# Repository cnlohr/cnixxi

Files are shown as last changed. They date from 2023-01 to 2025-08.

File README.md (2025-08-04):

# cnixxi

My experiment with nixie tubes.

It uses a ch32v003 to both control the nixie tube's cathodes, as well as provide the 180V supply for the nixie tube.

Youtube video:

Powering Nixies off USB with a 10¢ Micro (https://www.youtube.com/watch?v=-4d3PgEXhdY)

Schematic:

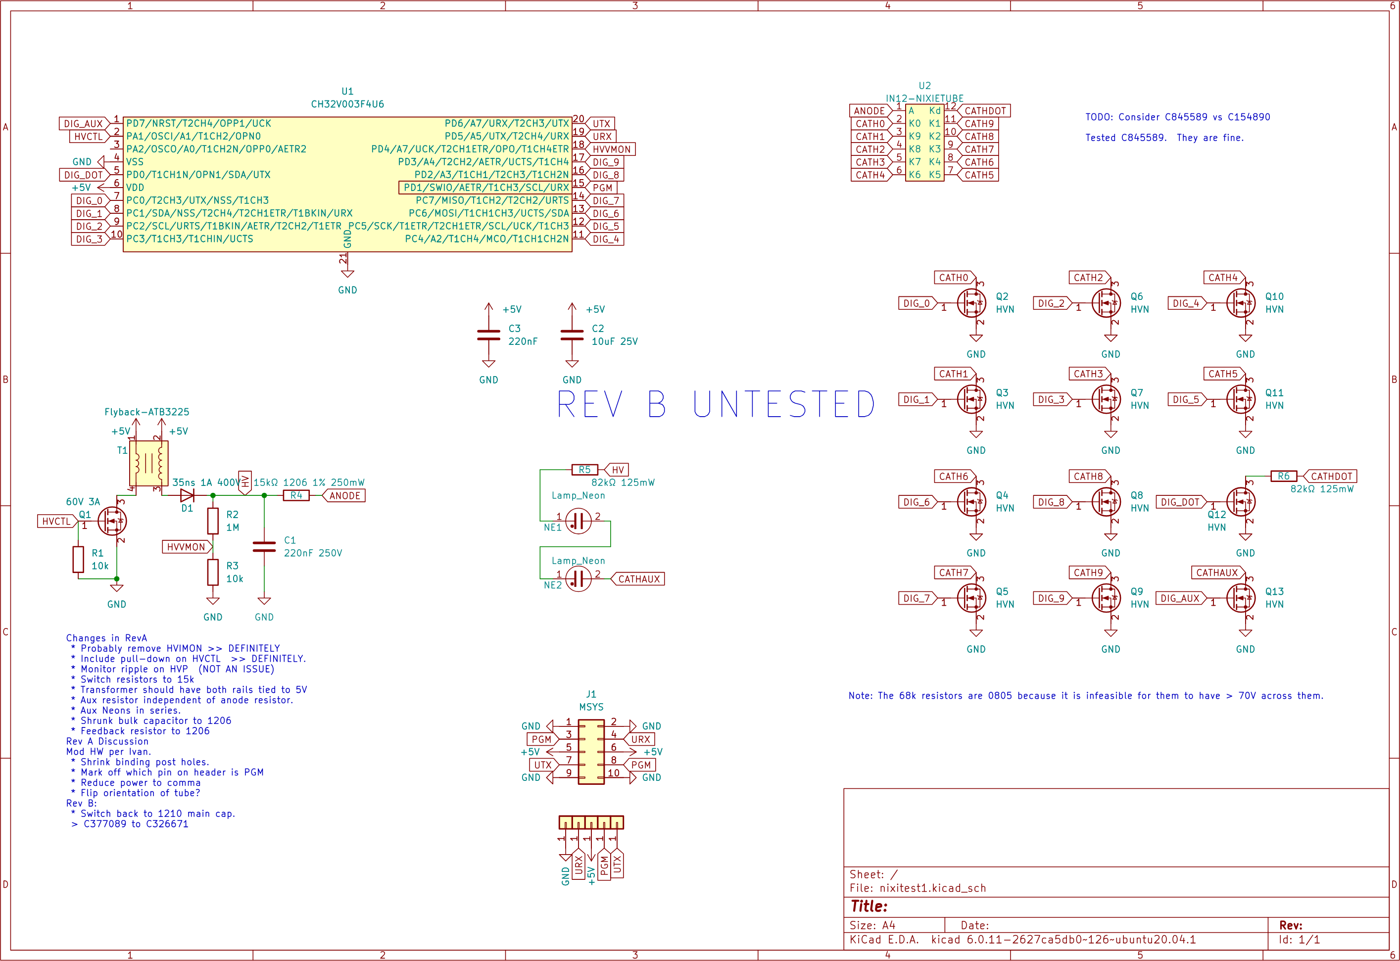
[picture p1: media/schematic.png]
schematic


Board:

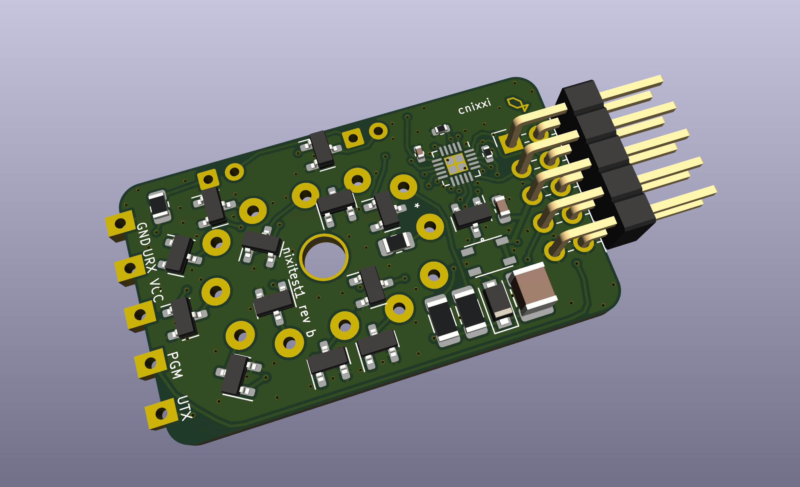
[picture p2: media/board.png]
board


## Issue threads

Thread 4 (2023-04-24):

Add wish list to core nixxi

cnlohr, 2023-04-24:
First: Use an extra IO pin to soldered header.

 * WS2812B Emulation
 * TX/RX Serial Protocol

cnlohr, 2023-04-24:
Use TXCO on main board. C427551 << Probably the winrar.

cnlohr, 2023-04-24:
It looks like C135223 is actually better?

cnlohr, 2023-04-24:
Also check C253754

cnlohr, 2023-04-28:
* Software-wise, try to use expected addition for de-noising the signal.  I.e. if tube is on apply constant offset.

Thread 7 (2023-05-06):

Love the concept - request for variation

LouDou, 2023-05-06:
Hi,

I saw this pop up on my YT feed - very interesting and love the concept of an addressable PWM driver for nixie tubes.

I actually have a small stash (now 14; I had 20 in total, but already built a clock using an off-the-shelf board which requires 6) of IN-17 tubes which are a bit smaller (and IMO way cuter :wink:) than the IN-12 you've used.

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

So, could the design be altered to suit the footprint of the IN-17? And is it electrically compatible?

Regards,
Doug

cnlohr, 2023-05-07:
Oh wow! Yes. It should be pretty portable. http://www.tube-tester.com/sites/nixie/dat_arch/IN-17_02.pdf

I also picked up a bunch of IN-4's.  I might poke around to see if I can figure something neat out.

isparkes, 2023-06-09:
IN-4s have a bad reputation for failing - they are not mercury doped and form whiskers between the digits after a while. IN-1 have the same problem. Not saying don't use them, just be aware that you should provide a way of easily changing the tubes , e.g. by using 1mm machine pins.

A possible optimisation: I have used BSS131 in the past for the cathode drivers - they are a bit cheaper and work just fine. I used them in this proof of concept back in 2018 https://bitbucket.org/isparkes/nixiemodulei2c/ - you'll notice that I used a higher cost controller back then, and managed to squeeze a NeoPixel into the design as well... :D

isparkes, 2023-06-09:
Oh, forgot to say what I actually wanted to say: Love what you've done with that controller! If there's anything I can help out with on with the Nixie specific stuff, feel free to ask. I've had a Nixie obsesession since 2018 or so and know my way around pretty well by now.

ImNoahDev, 2025-05-16:
I see its been a while but did you work this out? I was looking at making a variation for in13 tubes.

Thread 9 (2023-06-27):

Add PDF of schematic to repository?

jcwren, 2023-06-27:
Would you mind adding a PDF file of the schematic to the repo, please?

cnlohr, 2023-06-27:
It's here: https://github.com/cnlohr/cnixxi/blob/master/nixitest1/nixitest1.pdf

Or did I miss something?

jcwren, 2023-06-27:
Partially my bad :)  I was looking in `esp32s2-nixiehost`

cnlohr, 2023-06-28:
Oh, that's pretty separate.

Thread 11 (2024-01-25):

KiCad version

vzreagle, 2024-01-25:
Hi, I'm using KiCad 5.1.5 on Ubuntu 20.04 and can't open the schematics. Which version you are using? Thanks, nice project!

vzreagle, 2024-02-14:
Yes, I can use the PDF and make my own design, because I want to use only your high voltage generator for another function. But I want to know exactly what transistor you used, because I looked for one with similar characteristics (MOSFET N-CHANNEL 200V 1A) on Mouser and Digikey, and they are very expensive and with packages that do not work for me. Did you buy it at LCSC? could you provide the link? Thanks

cnlohr, 2024-02-15:
You can look into the production files here https://github.com/cnlohr/cnixxi/blob/master/nixitest1/nixitest1-revB.zip

The inner CSV has the BOM.

[nixitest1.csv](https://github.com/cnlohr/cnixxi/files/14289801/nixitest1.csv)

I ended up going with a C2938374 for the high-power switch and C845589 for the individual segments.

Closed 2024-02-01.

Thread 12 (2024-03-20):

Buy PCB premade

ImNoahDev, 2024-03-20:
Hi, Is there anywhere I can buy these driver PCBs pre-made. I would love to get some for my projects

jet438, 2025-05-02:
I too would like to know.

cnlohr, 2025-05-05:
You know... I made a couple.  I wonder if I can find them.  I'll leave this unresolved for the time being.  How many boards would you guys want if I did find them?

jet438, 2025-05-09:
Any update if you found the boards or not?

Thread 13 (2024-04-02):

Add USB control support over rv003usb

JustusFluegel, 2024-04-02:
Hi there, just came across your videos on youtube.

Since you released the `rv0003usb` library after this project was "complete" I thought it might make sense to use that here, if possible (note that I have not looked at the code thus far and I am not sure if for example the pid control loop and usb interrupt could interfere with each others timings in some way) and since you mentioned you wish to use this via usb in the video I just thought to at least throw the idea in the room.

Feel free to just ignore/close this if there is no interest in that, just a thing that  came across my mind :) ( and certainly don't feel pressured to make any changes here, if I wish to use this I can work on this myself (and create a pr afterwards if desired), again, this is just an idea that crossed my mind )

cnlohr, 2024-04-03:
To clarify, this project doesn't use usb at all, it uses a programmer to talk over the SWIO interface to alter the control loop, etc.

It would not be feasible to drive the nixi tube and also be a USB slave at the same time, it would cause serious timing issues in the feedback loop for the boost supply.

Sorry if that quashes any dreams.

JustusFluegel, 2024-04-03:
Fair enough, was kinda a long shot anyways (to clarify: I was aware that this doesn't use usb in it's current state, just was interested if it would be theoretically possible to add).

Thanks for taking your time to answer tho!

Closed 2024-04-03.

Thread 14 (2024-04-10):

Reason of using ADC injection channel for Vref

monte-monte, 2024-04-10:
Hi. I'm reading your code, trying to adapt it for my needs. Can you explain why do you read Vref in a separate injection group? What difference does it make compared to measuring both channels in the rule group?
Is it to read Vref on separate timer trigger after HVMON channel is converted?
Also I am reading the reference manual and there is this note:
```
Note: 1. When converting a rule group or injection group in intermittent mode, the conversion sequence does
not automatically start from the beginning when it ends. When all subgroups have been converted, the next
trigger event starts the conversion of the first subgroup.
2. You cannot use auto-injection (JAUTO=1) and intermittent mode at the same time.
```
So does it mean that Vref is being read 2 times in a row?
Also this line:
https://github.com/cnlohr/cnixxi/blob/d3db1aef0dade1c4579eeff3b5d0570b02ada58f/firmware/nixitest1/nixitest1.c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
contradicts the second paragraph of the note above.

Sorry if it's annoying, I am just confused "a little" :)

monte-monte, 2024-04-10:
Ok, so sometimes it's better to think a bit longer before asking questions:)
I guess you just want to have two registers with two voltages updated per every ADC interrupt, that's why injection mode.

But the second question stands: do ``ADC_JDISCEN`` and ``ADC_JEOCIE`` work together? And if they do, does injection group get sampled twice?

monte-monte, 2024-04-10:
So, I have made a simple boost converter, with an inductor instead of flyback transformer to drive 12-15V leds from 5V. I played with tuning values but couldn't get rid of visible brightness fluctuations that are visible when led is running at low power. I concluded, that it was not ripple from PWM but the PID truing to compensate.
First I increased sample time for feedback reading and decreased for VDD. Then I removed ``ADC_JDISCEN`` from ADC setup and now I don't have fluctuations even with simple version of your PID (that has only the proportional part).

monte-monte, 2024-04-11:
I used ADC DMA example from ch32v003fun to adapt this code to use DMA. Now ``SetupADC`` looks like this:
```
        // Configure ADC.
	// PD4 is analog input chl 7
	GPIOD->CFGLR &= ~(0xf<<(4*4));	// CNF = 00: Analog, MODE = 00: Input

	// Reset the ADC to init all regs
	RCC->APB2PRSTR |= RCC_APB2Periph_ADC1;
	RCC->APB2PRSTR &= ~RCC_APB2Periph_ADC1;

	// ADCCLK = 12 MHz => RCC_ADCPRE divide by 4
	RCC->CFGR0 &= ~RCC_ADCPRE;  // Clear out the bis in case they were set
	RCC->CFGR0 |= RCC_ADCPRE_DIV4;	// set it to 010xx for /4.

	// Set up single conversion on chl 7
	ADC1->RSQR1 = (ADC_NUMCHLS-1) << 20;
	ADC1->RSQR2 = 0;
	ADC1->RSQR3 = (7<<(5*0)) | (8<<(5*1));

	// Sampling time for channels. Careful: This has PID tuning implications.
	// Note that with 3 and 3,the full loop (and injection) runs at 138kHz.
	ADC1->SAMPTR2 = (1<<(3*7)) | (1<<(3*8));
		// 0:7 => 3/9/15/30/43/57/73/241 cycles
		// (4 == 43 cycles), (6 = 73 cycles)  Note these are alrady /2, so
		// setting this to 73 cycles actually makes it wait 256 total cycles
		// @ 48MHz.

	// Turn on ADC and set rule group to sw trig
	// 0 = Use TRGO event for Timer 1 to fire ADC rule.
	ADC1->CTLR2 = ADC_ADON | ADC_EXTTRIG | ADC_DMA;

	// Reset calibration
	ADC1->CTLR2 |= ADC_RSTCAL;
	while(ADC1->CTLR2 & ADC_RSTCAL);

	// Calibrate ADC
	ADC1->CTLR2 |= ADC_CAL;
	while(ADC1->CTLR2 & ADC_CAL);

	// Turn on DMA
	RCC->AHBPCENR |= RCC_AHBPeriph_DMA1;

	//DMA1_Channel1 is for ADC
	DMA1_Channel1->PADDR = (uint32_t)&ADC1->RDATAR;
	DMA1_Channel1->MADDR = (uint32_t)adc_buffer;
	DMA1_Channel1->CNTR  = ADC_NUMCHLS;
	DMA1_Channel1->CFGR  =
		DMA_M2M_Disable |
		DMA_Priority_VeryHigh |
		DMA_MemoryDataSize_HalfWord |
		DMA_PeripheralDataSize_HalfWord |
		DMA_MemoryInc_Enable |
		DMA_Mode_Circular |
		DMA_DIR_PeripheralSRC;

	// Turn on DMA channel 1
	DMA1_Channel1->CFGR |= DMA_CFGR1_EN;

	// enable the ADC Conversion Complete IRQ
	NVIC_EnableIRQ( ADC_IRQn );

	// ADC_JEOCIE: Enable the End-of-conversion interrupt.
	// ADC_SCAN: Allow scanning.
	ADC1->CTLR1 = ADC_EOCIE | ADC_SCAN;
```

And in ``ADC1_IRQHandler`` I read values from ``adc_buffer[0]`` and ``adc_buffer[1]`` respectively. Now everything works even with low sampling time, but with my hardware setup I still get better result from using just proportional part of PID. If I try to use full PID I get brightness fluctuations that are not reflected in voltage monitor in ``testnix`` app. I guess I'd need to dive deeper into PID tuning for it to work perfectly for me, but for now I don't see much reason. But I'd like to better understand what causes this difference in behavior.
When using full PID it seems like timing of ADC reads plays a big role, such if I change sampling times I see different behavior, with only proportional I don't see any visible change.
The next step will be to try implement constant current mode with use of another ADC channel and built-in OPAMP.

monte-monte, 2024-04-13:
Continuing tinkering I've soldered 3.3V LDO to supply power from the same source as the boost part of the circuit (before MCU was powered via WCH-link). Now I see a slight brightness ripple at low power. I've concluded that the noisy VDD readings are a culprit here. If I set VDD hardcoded to 3.3V value the brightness ripple is gone.
BUT! The strange part event with live VDD readings the ripple is only present when testnix app is running. If I close the app, even without detaching a probe, the ripple is gone. So does DMDATA0 reads and writes introduce some timing lag, or what? I haven't got an oscilloscope, so I can't accurately test such fast signals.

cnlohr, 2024-04-22:
I am so sorry, I have been so heads down on porting the ch32x035 stuff, I have been neglecting my github...  But to summarize things for anyone else coming along,

1. I measure VCC with the injection, because VCC is the voltage reference for all other measurements, you need to know your VCC if you want to know the voltage of your other measured voltages.
2. I regret that I don't recall the specifics surrounding how the injection stuff works, I barely understood it when I wrote the code to begin with :(
3. Looking at your code, I am still unclear what it's measuring with the rule and what it's measuring with the injection.
4. **ADC TIMING MATTERS MASSIVELY**  You MUST align your ADC sampling with your PWM switch.  For some applications it must be on the "on" and others it must be on the "off" but the ADC should be aligned to whatever is unaffected by pulse width. Failure to do this will easily increase your measured noise by an order of magnitude!!!  Please note also - your ideal sample time might be inverted to mine.
5. I have never seen issues writing/reading from DMDATA0 - but now you have me worried.  It is entirely possible that there could be some unintuitive impact on the system by reading/writing from DMDATA0.

Thinking forward - I wonder if there is some other scheme that would let you align all of your voltage readings. I.e. move everything to the injection, and chain it all off the rule?  Or maybe manually reconfigure the ADC every interrupt to switch between the regular ADC reading and the VDD reading.

Also, also, if you know you have a fixed LDO, then there should be no need to monitor VDD at all, and you can simplify the system immensely.

SIDE NOTE: If you would like a much better place for discussion is the #ch32v003 channel in my discord... I can give you access if you want, my user name is `cnlohr`

monte-monte, 2024-04-25:
@cnlohr no worries, I glad I mostly figured out myself, that's better for understanding :)

> 3\. Looking at your code, I am still unclear what it's measuring with the rule and what it's measuring with the injection

In my code I don't use injection at all, that's what I was getting at. I've found that without injection I can decrease sampling time and it somehow decreases noise on both ADC readings. Injection itself introduces delay when it is called automatically after rule reading. I guess it messes timing, because getting rid of it improved things in my case. I wonder if it will work with your hardware better/worse.

> 4\. You MUST align your ADC sampling with your PWM switch

Yes, I get this, I've read your comments in code several dozens times while trying understand it :) In current setup ADC read starts on timer rollover, so is there any other way to adjust read timing apart from changing sampling time and/or introducing other channel reads before the one we measuring?

> 5\. I have never seen issues writing/reading from DMDATA0 - but now you have me worried.  It is entirely possible that there could be some unintuitive impact on the system by reading/writing from DMDATA0.

I don't have a clue, I just report what I see, can it somehow skew ADC read timings?

> Also, also, if you know you have a fixed LDO, then there should be no need to monitor VDD at all, and you can simplify the system immensely.

That's what I figured out in the end :)

> If you would like a much better place for discussion is the #ch32v003 channel in my discord

Should I add you in discord, or just give you my username here (_montemonte_)? I'm not very familiar with it specifics.

cnlohr, 2024-04-25:
Re: No Injection: @monte-monte this is extremely interesting - how do you make sure to maintain alignment of the samples?
Re: Rollover: You can also sync the timer off of a channel compare. You aren't limited to TRGO.
Re: I don't have any idea how reading/write DMDATA0 could affect things.  You may need to peel things back.  I just did a bunch of testing last night and could not repro.  My data seemed to be just fine?
Re: Just add me on Discord.  I will send you an invite.

monte-monte, 2024-04-25:
> how do you make sure to maintain alignment of the samples?

Alignment to what? As I understand, rollover happens -> TRGO triggers ADC conversions -> ADC converts 2 channels one after another in one go adding values to array via DMA -> interrupt is triggered.
So basically all I did was: activated DMA and added second channel to rule group and removed code for injection. Now you make me think I am doing something wrong :) but hey, everything works (somehow).

> You may need to peel things back. I just did a bunch of testing last night and could not repro

It may have something to do with hardware part that is different in my setup. So basically I see some shimmering of the LED only on the lowest values that keeps it lit, so it has to be a very low current at that point. Maybe it connected to inductor saturation, or how mosfet opens/closes at different conditions, idk my knowledge and experience is not enough to accurately evaluate this behavior. All I know it that when testnix monitor is running I have this shimmer and when I close it shimmer is gone. And it's only when using measured VCC as the baseline, if I hardcode the voltage value I see no issues. So I guess not really an issue after all, but an interesting thing to understand what causes it.

cnlohr, 2024-04-26:
Alignment:  I just meant if you wanted you could trigger off of a timer compare match on an unused timer compare channel instead of TRGO.

I really don't know what could be going on with your shimmer issue.

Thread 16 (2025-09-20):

Transformer should not have both rails tied to 5V

wkrysmann, 2025-09-20:
I'm looking at the Flyback schematic and I'm scratching my head on why both sides of transfer are connected to 5V? This looks like shorting HV rail to 5V rail. Am I missing something?
You've also made a comment @cnlohr  "Transformer should have both rails tied to 5V" which doesn't sound right.

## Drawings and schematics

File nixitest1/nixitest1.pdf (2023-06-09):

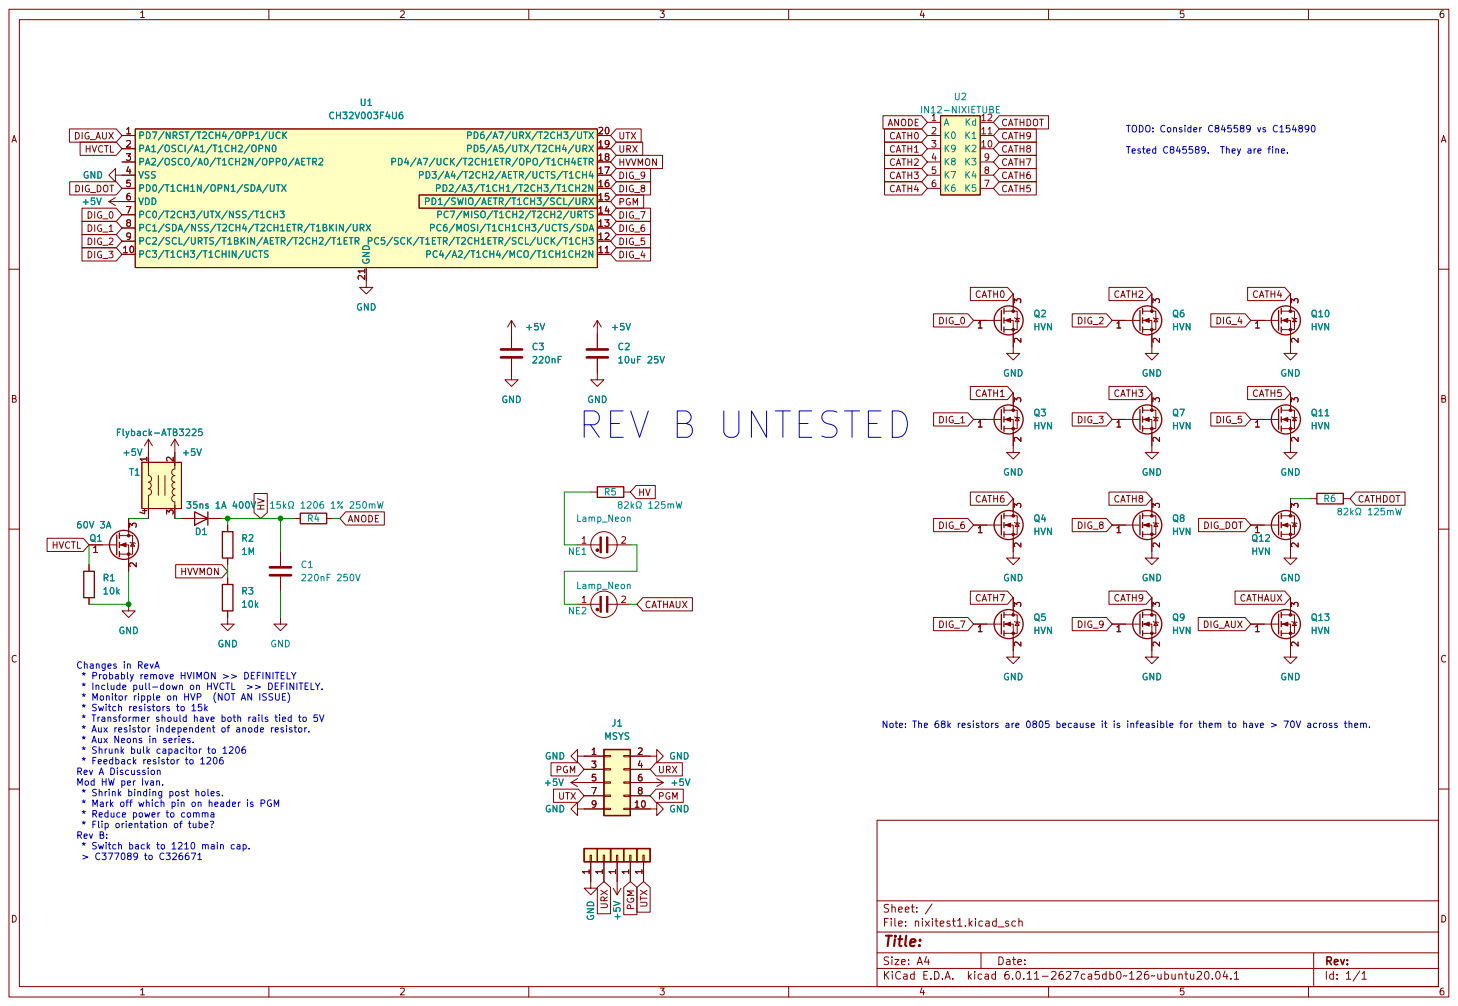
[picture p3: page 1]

Changes in RevA
* Probably remove HVIMON >> DEFINITELY

* Reduce power to comma

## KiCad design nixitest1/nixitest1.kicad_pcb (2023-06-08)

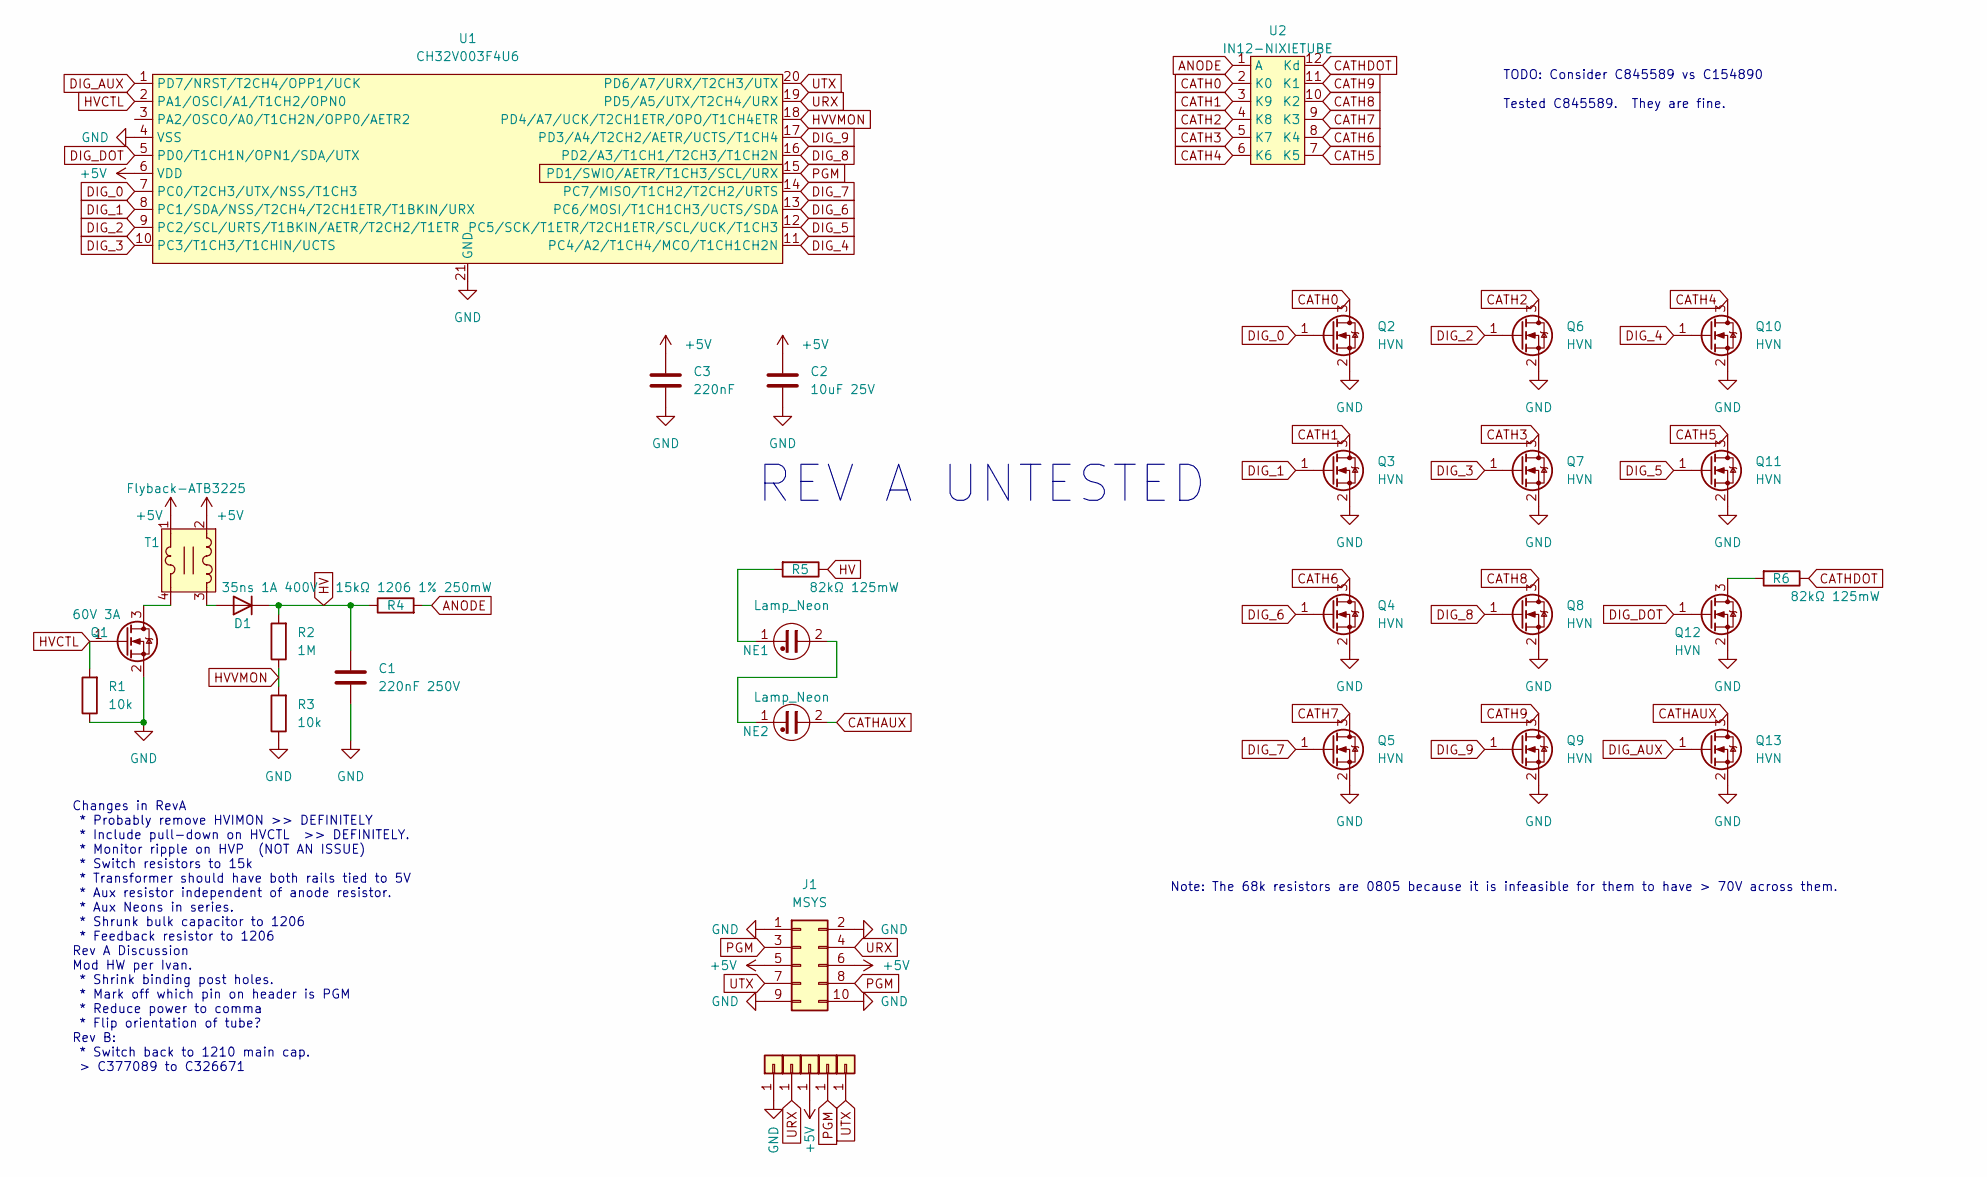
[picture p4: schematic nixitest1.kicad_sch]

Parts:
C1: 220nF 250V; C_1210_3225Metric; LCSC C326671
C2: 10uF 25V; C_0603_1608Metric; LCSC C96446
C3: 220nF; C_0402_1005Metric; LCSC C16772
D1: 35ns 1A 400V; D_SOD-123F; LCSC C128697
J1: MSYS; PinHeader_2x05_P2.54mm_Horizontal; LCSC C239336
J2, J3, J4, J5, J6: rawpad22
NE1, NE2: Lamp_Neon; neonglow
Q1: 60V 3A; SOT-23; LCSC C2938374
Q2, Q3, Q4, Q5, Q6, Q7, Q8, Q9, Q10, Q11, Q12, Q13: HVN; SOT-23; LCSC C845589
R1, R3: 10k; R_0402_1005Metric; LCSC C25744
R2: 1M; R_1206_3216Metric; LCSC C108083
R4: 15kΩ 1206 1% 250mW; R_1206_3216Metric; LCSC C114932
R5, R6: 82kΩ 125mW; R_0805_2012Metric; LCSC C136904
T1: Flyback-ATB3225; LCSC C415291
U1: CH32V003F4U6; QFN-20-1EP_3x3mm_P0.4mm_EP1.65x1.65mm; LCSC C5299908
U2: IN12-NIXIETUBE; IN12-NIXIE

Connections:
+5V: C2.1, C3.1, J1.5, J1.6, J3.1, T1.1, T1.2, U1.6 (VDD)
ANODE: R4.2, U2.1 (A)
CATH0: Q2.3 (D), U2.2 (K0)
CATH1: Q3.3 (D), U2.3 (K9)
CATH2: Q6.3 (D), U2.4 (K8)
CATH3: Q7.3 (D), U2.5 (K7)
CATH4: Q10.3 (D), U2.6 (K6)
CATH5: Q11.3 (D), U2.7 (K5)
CATH6: Q4.3 (D), U2.8 (K4)
CATH7: Q5.3 (D), U2.9 (K3)
CATH8: Q8.3 (D), U2.10 (K2)
CATH9: Q9.3 (D), U2.11 (K1)
CATHAUX: NE2.2, Q13.3 (D)
CATHDOT: R6.1, U2.12 (Kd)
DIG_0: Q2.1 (G), U1.7 (PC0/T2CH3/UTX/NSS/T1CH3)
DIG_1: Q3.1 (G), U1.8 (PC1/SDA/NSS/T2CH4/T2CH1ETR/T1BKIN/URX)
DIG_2: Q6.1 (G), U1.9 (PC2/SCL/URTS/T1BKIN/AETR/T2CH2/T1ETR)
DIG_3: Q7.1 (G), U1.10 (PC3/T1CH3/T1CHIN/UCTS)
DIG_4: Q10.1 (G), U1.11 (PC4/A2/T1CH4/MCO/T1CH1CH2N)
DIG_5: Q11.1 (G), U1.12 (PC5/SCK/T1ETR/T2CH1ETR/SCL/UCK/T1CH3)
DIG_6: Q4.1 (G), U1.13 (PC6/MOSI/T1CH1CH3/UCTS/SDA)
DIG_7: Q5.1 (G), U1.14 (PC7/MISO/T1CH2/T2CH2/URTS)
DIG_8: Q8.1 (G), U1.16 (PD2/A3/T1CH1/T2CH3/T1CH2N)
DIG_9: Q9.1 (G), U1.17 (PD3/A4/T2CH2/AETR/UCTS/T1CH4)
DIG_AUX: Q13.1 (G), U1.1 (PD7/NRST/T2CH4/OPP1/UCK)
DIG_DOT: Q12.1 (G), U1.5 (PD0/T1CH1N/OPN1/SDA/UTX)
GND: C1.2, C2.2, C3.2, J1.1, J1.2, J1.9, J1.10, J2.1, Q1.2 (S), Q2.2 (S), Q3.2 (S), Q4.2 (S), Q5.2 (S), Q6.2 (S), Q7.2 (S), Q8.2 (S), Q9.2 (S), Q10.2 (S), Q11.2 (S), Q12.2 (S), Q13.2 (S), R1.1, R3.1, U1.4 (VSS), U1.21 (GND)
HV: C1.1, D1.1 (K), R2.2, R4.1, R5.1
HVCTL: Q1.1 (G), R1.2, U1.2 (PA1/OSCI/A1/T1CH2/OPN0)
HVVMON: R2.1, R3.2, U1.18 (PD4/A7/UCK/T2CH1ETR/OPO/T1CH4ETR)
unnamed: D1.2 (A), T1.3
unnamed: NE1.1, R5.2
unnamed: NE1.2, NE2.1
unnamed: Q1.3 (D), T1.4
unnamed: Q12.3 (D), R6.2
PGM: J1.3, J1.8, J5.1, U1.15 (PD1/SWIO/AETR/T1CH3/SCL/URX)
URX: J1.4, J4.1, U1.19 (PD5/A5/UTX/T2CH4/URX)
UTX: J1.7, J6.1, U1.20 (PD6/A7/URX/T2CH3/UTX)

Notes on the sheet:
TODO: Consider C845589 vs C154890 Tested C845589. They are fine.
Changes in RevA * Probably remove HVIMON >> DEFINITELY * Include pull-down on HVCTL >> DEFINITELY. * Monitor ripple on HVP (NOT AN ISSUE) * Switch resistors to 15k * Transformer should have both rails tied to 5V * Aux resistor independent of anode resistor. * Aux Neons in series. * Shrunk bulk capa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
REV A UNTESTED
Note: The 68k resistors are 0805 because it is infeasible for them to have > 70V across them.

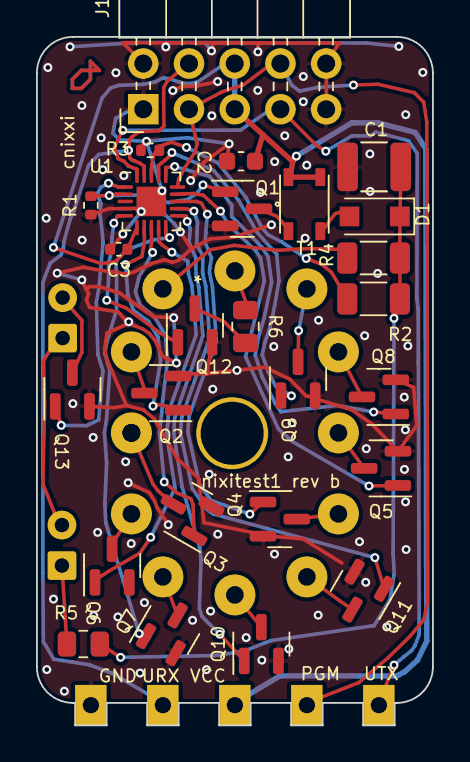
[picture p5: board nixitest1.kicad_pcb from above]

Board: 2 copper layers, 22.0 x 38.2 mm, 34 parts (0 on the bottom side), 38 nets.

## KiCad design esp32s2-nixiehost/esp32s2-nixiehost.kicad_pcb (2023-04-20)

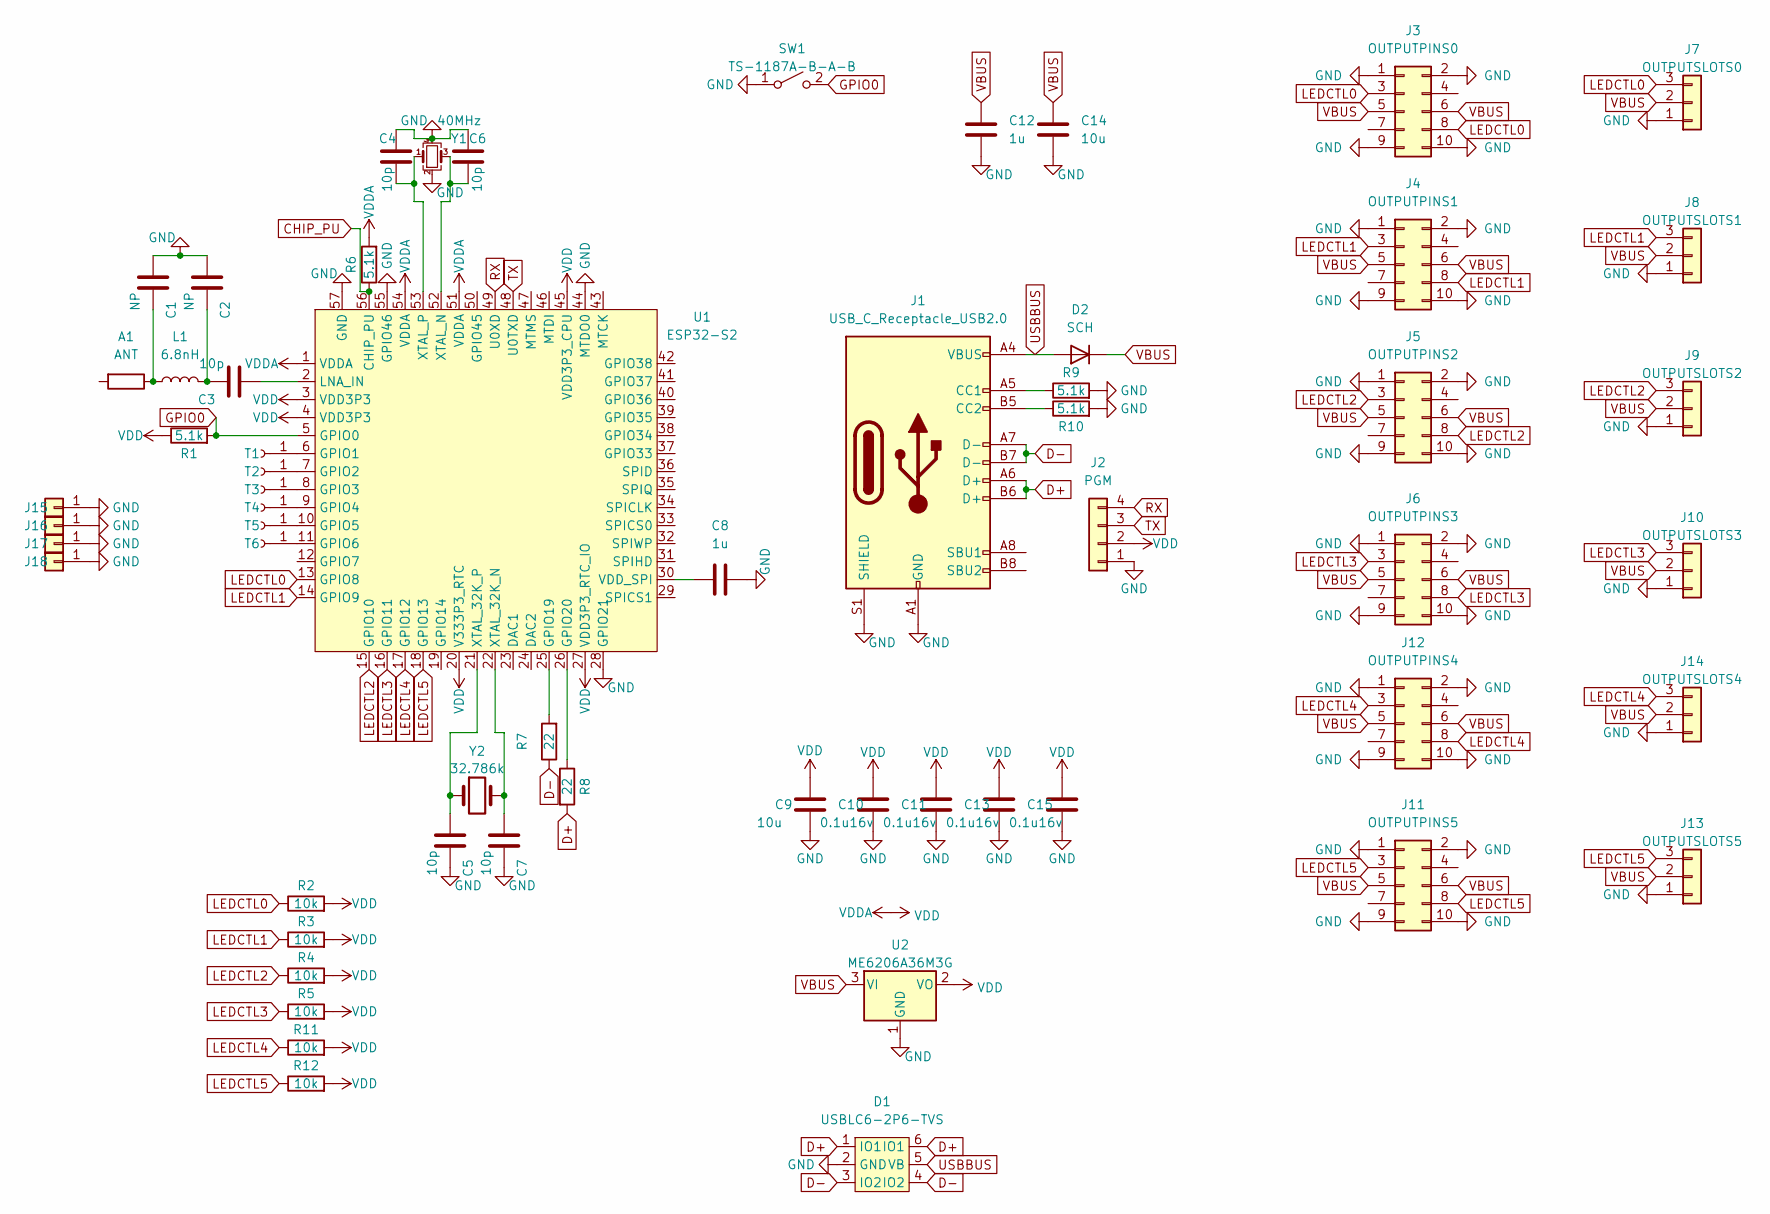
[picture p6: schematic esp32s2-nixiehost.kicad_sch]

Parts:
A1: ANT; R_1206_3216Metric; LCSC C127629
C1, C2: NP; C_0402_1005Metric; LCSC C106199
C3, C4, C5, C6, C7: 10p; C_0402_1005Metric; LCSC C106199
C8, C12: 1u; C_0402_1005Metric; LCSC C106254
C9: 10u; C_0402_1005Metric; LCSC C315248
C10, C11, C13, C15: 0.1u16v; C_0402_1005Metric; LCSC C338032
C14: 10u; C_0603_1608Metric; LCSC C18800
D1: USBLC6-2P6-TVS; SOT-666; LCSC C2827693
D2: SCH; D_SOD-123F; LCSC C115330
J1: USB_C_Receptacle_USB2.0; USB_C_Receptacle_HRO_TYPE-C-31-M-12; LCSC C2765186
J2: PGM; PinHeader_1x04_P2.54mm_Vertical; LCSC NP
J3: OUTPUTPINS0; PinSocket_2x05_P2.54mm_Vertical_SMD; LCSC C843271
J4: OUTPUTPINS1; PinSocket_2x05_P2.54mm_Vertical_SMD; LCSC C843271
J5: OUTPUTPINS2; PinSocket_2x05_P2.54mm_Vertical_SMD; LCSC C843271
J6: OUTPUTPINS3; PinSocket_2x05_P2.54mm_Vertical_SMD; LCSC C843271
J7: OUTPUTSLOTS0; nixiehostslot
J8: OUTPUTSLOTS1; nixiehostslot
J9: OUTPUTSLOTS2; nixiehostslot
J10: OUTPUTSLOTS3; nixiehostslot
J11: OUTPUTPINS5; PinSocket_2x05_P2.54mm_Vertical_SMD; LCSC C843271
J12: OUTPUTPINS4; PinSocket_2x05_P2.54mm_Vertical_SMD; LCSC C843271
J13: OUTPUTSLOTS5; nixiehostslot
J14: OUTPUTSLOTS4; nixiehostslot
J15, J16, J17, J18: MountingHole_3.5mm_Pad
L1: 6.8nH; L_0402_1005Metric; LCSC C77110
R1, R6, R9, R10: 5.1k; R_0402_1005Metric; LCSC C105872
R2, R3, R4, R5, R11, R12: 10k; R_0402_1005Metric; LCSC C25086
R7, R8: 22; R_0402_1005Metric; LCSC C25092
SW1: TS-1187A-B-A-B; SW_SPST_TL3342; LCSC C318884
T1, T2, T3, T4, T5, T6: TOUCH; TouchExposed6
U1: ESP32-S2; ESP32S2; LCSC C2840995
U2: ME6206A36M3G; SOT-23; LCSC C236698
Y1: 40MHz; Crystal_SMD_2016-4Pin_2.0x1.6mm; LCSC C648970
Y2: 32.786k; Crystal_SMD_2012-2Pin_2.0x1.2mm; LCSC C99009

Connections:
CHIP_PU: R6.1, U1.56 (CHIP_PU)
D+: D1.1 (IO1), D1.6 (IO1), J1.A6 (D+), J1.B6 (D+), R8.2
D-: D1.3 (IO2), D1.4 (IO2), J1.A7 (D-), J1.B7 (D-), R7.1
GND: C1.2, C2.2, C4.1, C5.1, C6.1, C7.1, C8.2, C9.2, C10.2, C11.2, C12.1, C13.2, C14.2, C15.2, D1.2 (GND), J1.A1 (GND), J1.A12 (GND), J1.B1 (GND), J1.B12 (GND), J1.S1 (SHIELD), J2.1, J3.1, J3.2, J3.9, J3.10, J4.1, J4.2, J4.9, J4.10, J5.1, J5.2, J5.9, J5.10, J6.1, J6.2, J6.9, J6.10, J7.1, J8.1, J9.1, J10.1, J11.1, J11.2, J11.9, J11.10, J12.1, J12.2, J12.9, J12.10, J13.1, J14.1, J15.1, J16.1, J17.1, J18.1, R9.2, R10.2, SW1.1 (A), U1.28 (GPIO21), U1.44 (MTDO0), U1.55 (GPIO46), U1.57 (GND), U2.1 (GND), Y1.2, Y1.4
GPIO0: R1.2, SW1.2 (B), U1.5 (GPIO0)
LEDCTL0: J3.3, J3.8, J7.3, R2.1, U1.13 (GPIO8)
LEDCTL1: J4.3, J4.8, J8.3, R3.1, U1.14 (GPIO9)
LEDCTL2: J5.3, J5.8, J9.3, R4.1, U1.15 (GPIO10)
LEDCTL3: J6.3, J6.8, J10.3, R5.1, U1.16 (GPIO11)
LEDCTL4: J12.3, J12.8, J14.3, R11.1, U1.17 (GPIO12)
LEDCTL5: J11.3, J11.8, J13.3, R12.1, U1.18 (GPIO13)
unnamed: A1.1, C1.1, L1.1
unnamed: C2.1, C3.1, L1.2
unnamed: C3.2, U1.2 (LNA_IN)
unnamed: C4.2, U1.53 (XTAL_P), Y1.1
unnamed: C5.2, U1.21 (XTAL_32K_P), Y2.1
unnamed: C6.2, U1.52 (XTAL_N), Y1.3
unnamed: C7.2, U1.22 (XTAL_32K_N), Y2.2
unnamed: C8.1, U1.30 (VDD_SPI)
unnamed: J1.A5 (CC1), R9.1
unnamed: J1.B5 (CC2), R10.1
unnamed: R7.2, U1.25 (GPIO19)
unnamed: R8.1, U1.26 (GPIO20)
unnamed: T1.1, U1.6 (GPIO1)
unnamed: T2.1, U1.7 (GPIO2)
unnamed: T3.1, U1.8 (GPIO3)
unnamed: T4.1, U1.9 (GPIO4)
unnamed: T5.1, U1.10 (GPIO5)
unnamed: T6.1, U1.11 (GPIO6)
RX: J2.4, U1.49 (U0XD)
TX: J2.3, U1.48 (U0TXD)
USBBUS: D1.5 (VB), D2.2 (A), J1.A4 (VBUS), J1.A9 (VBUS), J1.B4 (VBUS), J1.B9 (VBUS)
VBUS: C12.2, C14.1, D2.1 (K), J3.5, J3.6, J4.5, J4.6, J5.5, J5.6, J6.5, J6.6, J7.2, J8.2, J9.2, J10.2, J11.5, J11.6, J12.5, J12.6, J13.2, J14.2, U2.3 (VI)
VDD: C9.1, C10.1, C11.1, C13.1, C15.1, J2.2, R1.1, R2.2, R3.2, R4.2, R5.2, R6.2, R11.2, R12.2, U1.1 (VDDA), U1.3 (VDD3P3), U1.4 (VDD3P3), U1.20 (V333P3_RTC), U1.27 (VDD3P3_RTC_IO), U1.45 (VDD3P3_CPU), U1.51 (VDDA), U1.54 (VDDA), U2.2 (VO)

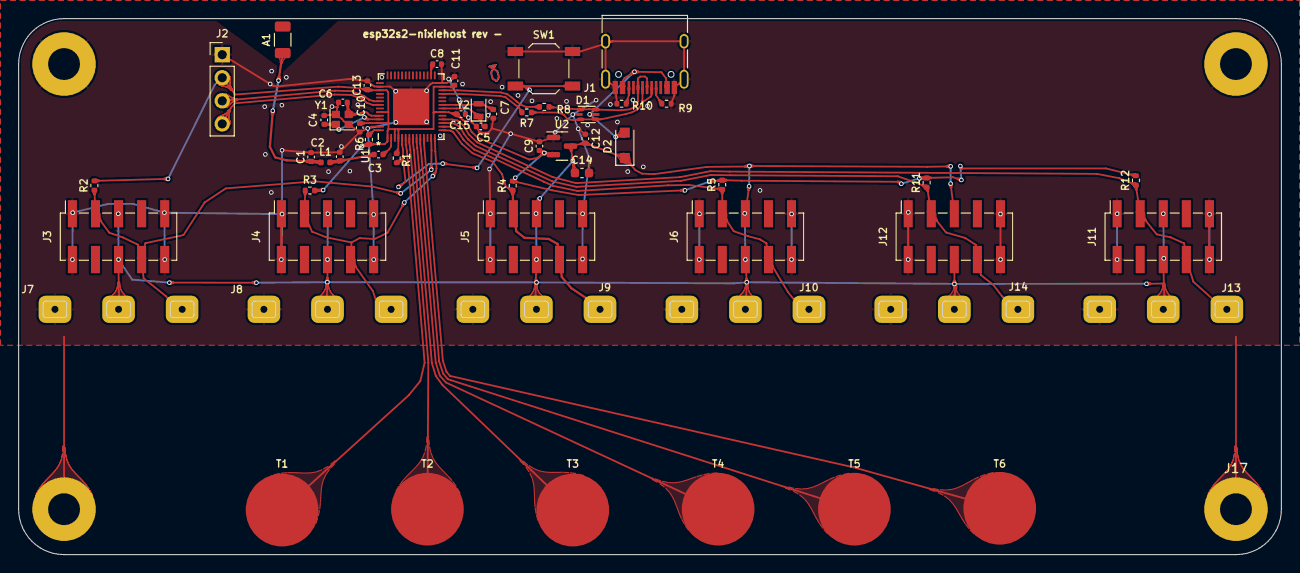
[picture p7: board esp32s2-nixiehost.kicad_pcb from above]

Board: 2 copper layers, 139.0 x 59.0 mm, 60 parts (0 on the bottom side), 34 nets.

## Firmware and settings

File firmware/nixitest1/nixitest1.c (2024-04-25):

//
// cnixi - ch32v003 base driver for IN-15 nixie tubes.
//
// Fully integrated PI flyback PSU controller + Nixie Tube output
// control with up to 2 channel simultaneous dimming.
//
// Copyright 2023 <>< Charles Lohr, under the MIT-X11 license or NewBSD
// license, you choose.
//
// Note: Before running this, you should run the optionbytes folder script
// in order configure RESET as a GPIO so you can use the AUX input as well
// as forcing the watchdog on by default. 
//

#define SYSTEM_CORE_CLOCK 48000000

#include "ch32v003fun.h"
#include <stdio.h>

static uint16_t GenOnMask( int segmenton );
static void ApplyOnMask( uint16_t onmask );
static inline void WatchdogPet();

// Limits the "ADC Set Value" in volts.
// This prevents us from exceeding 190 volts target.
#define ABSOLUTE_MAX_ADC_SET 190

// Do not mess with PWM_ values unless you know what you are willing to go down
// a very deep rabbit hole. I experimentally determined 140 for this particular
// system was on the more efficient side of things and gave good dynamic range.
// 140 means it's 48MHz / 140 = 342 kHz for the main flyback frequency.
//
// You can explore values by doing ENABLE_TUNING in here and in testnix.c
// #define ENABLE_TUNING
#ifndef ENABLE_TUNING
#define PWM_PERIOD 140
#else
int PWM_PERIOD = 140;
#endif
int pwm_max_duty = 48;  //This is changed based on vdd.


// Flyback PID loop Tuning Parameters
//
// This is a PID loop (you should read about this separately). But these terms
// are actually on the order of 2^term. So we are only able to get the tuning
// to a rough ballpark. Thankfully, PID loops are forgiving.
//
// Honestly, this is MUCH more sophisticated than it needs to be!  I was using
// a P-only loop for quite some time without any issues.
#define ERROR_P_TERM 2  // Actually 2^2
#define ERROR_D_TERM -1  // Actually 2^0
#define I_SAT_MAX (4096+2048) // SAT * 2^(-ADC_IIR+ERROR_I_TERM) = Max impact to PWM
#define I_SAT_MIN (-4096)
#define ERROR_I_TERM -5 // Actually 2^-6

// We filter our ADC inputs because they are kind of noisy.
//
// We can use Binary-shift IIR filters to filter the incoming ADC signals.
// See later in the code, but, it maps to only about 4 assembly instructions!
// (plus a read-back of the previous value we will be mixing).
#define ADC_IIR 2
#define VDD_IIR 2

// Target feedback, set by the user.
int target_feedback = 0;

// Feedback based on what the user set and the part's VDD.
int feedback_vdd = 0;

// Filtered ADC and VDD values.
int lastadc = 0;
int lastrefvdd = 0;

// Code for handling numeric fading, between 2 numbers or alone.

uint16_t fade_time0, fade_time1;
uint16_t fade_disp0, fade_disp1;

static uint32_t HandleFade( uint8_t fadepos )  __attribute__((section(".srodata")));
static uint32_t HandleFade( uint8_t fadepos )
{
	// Digit fade.  Use fade_timeX and fade_dispX to handle fade logic.
	if( fadepos < fade_time0 )
		return fade_disp0;
	else if( fadepos < fade_time1 ) 
		return fade_disp1;
	else
		return 0;
}

static inline uint32_t FastMultiply( uint32_t big_num, uint32_t small_num );
static inline uint32_t FastMultiply( uint32_t big_num, uint32_t small_num )
{
	// The CH32V003 is an EC core, so no hardware multiply. GCC's way multiply
	// is slow, so I wrote this.
	//
	// This basically does this:
	//	return small_num * big_num;
	//
	// Note: This does NOT check for zero to begin with, though this still
	// produces the correct results, it is a little weird that even if
	// small_num is zero it executes once.
	//
	// Additionally note, instead of the if( m&1 ) you can do the following:
	//  ret += multiplciant & neg(multiplicand & 1).
	//
	// BUT! Shockingly! That is slower than an extra branch! The CH32V003
	//  can branch unbelievably fast.
	//
	// This is functionally equivelent and much faster.
	//
	// Perf numbers, with small_num set to 180V.
	//  No multiply:         21.3% CPU Usage
	//  Assembly below:      42.4% CPU Usage  (1608 bytes for whole program)
	//  C version:           41.4% CPU Usage  (1600 bytes for whole program)
	//  Using GCC (__mulsi3) 65.4% CPU Usage  (1652 bytes for whole program)
	//
	// The multiply can be done manually:
	uint32_t ret = 0;
	uint32_t multiplicand = small_num;
	uint32_t mutliplicant = big_num;
	do
	{
		if( multiplicand & 1 )
			ret += mutliplicant;
		mutliplicant<<=1;
		multiplicand>>=1;
	} while( multiplicand );
	return ret;

	// Which is equivelent to the following assembly (If you were curious)
/*
	uint32_t ret = 0;
	asm volatile( "\n\
		.option   rvc;\n\
	1:	andi t0, %[small], 1\n\
		beqz t0, 2f\n\
		add %[ret], %[ret], %[big]\n\
	2:	srli %[small], %[small], 1\n\
		slli %[big], %[big], 1\n\
		bnez %[small], 1b\n\
	" :
		[ret]"=&r"(ret), [big]"+&r"(big_num), [small]"+&r"(small_num) : :
		"t0" );
	return ret;
*/
}

// FYI You can use functions in ram to make them work faster.  The .srodata
// attribute. This means this function gets placed into RAM. Normally this
// function takes approximately 2.5-3us to execute from flash, but only 2-2.5us
// to execute from RAM.

// This is an interrupt called by an ADC conversion.
void ADC1_IRQHandler(void)
	__attribute__((interrupt))
	__attribute__((section(".srodata")));

void ADC1_IRQHandler(void)
{
	// If you want to see how long this functon takes to run, you can use a
	// scope and then monitor pin D6 if you uncomment this and the bottom copy.
	GPIOD->BSHR = 1<<6;

	// Acknowledge pending interrupts.
	// This will always be ADC_JEOC, so we don't need to check.
	ADC1->STATR = 0;

	// Acknowledge the interrupt.
	
	// It is crucial that our ADC sample is ALWAYS ALIGNED to the PWM, that way
	// any ripple and craziness that happens from the chopping of the flyback
	// is completely filtered out because of where we are sampling.

	// This performs a low-pass filter on our data, ADC1->RDATAR the sample
	// rate, always.  As a side note, the value of the IIR (but now it's
	// 2^VDD_IIR bigger)

	int adcraw = ADC1->RDATAR;
	int newadc = adcraw + (lastadc - (lastadc>>ADC_IIR));
	lastadc = newadc;

	int err = feedback_vdd - lastadc;

	static int integral;
	static int lasterr;
	int derivative = (err - lasterr);
	lasterr = err;
	integral += err;

	// We asymmetrically allow the integral to saturate, to help prevent long-
	// term oscillations.
	integral = ( integral > ((I_SAT_MAX)<<ADC_IIR) ) ? ((I_SAT_MAX)<<ADC_IIR) : integral;
	integral = ( integral < ((I_SAT_MIN)<<ADC_IIR) ) ? ((I_SAT_MIN)<<ADC_IIR) : integral;

	// This is the heart of the PID loop.
	// General note about shifting: Be sure to combine your shifts.
	// If you shift right, then left, you will lose bits of precision.
	// These shifts turn into single left and right immediate shifts.
	int plant = 
		(err << ( (-ADC_IIR) + (ERROR_P_TERM) )) +
		(integral >> ( ADC_IIR - (ERROR_I_TERM) )) +
		(derivative >> ( (ADC_IIR) - (ERROR_D_TERM) ) );
	plant = ( plant > pwm_max_duty ) ? pwm_max_duty : plant;
	plant = ( plant < 0 ) ? 0 : plant;
	TIM1->CH2CVR = plant;

	// Use injection channel data to read vref.  This is needed because we
	// measure all values WRT to VDD and GND.  So we need to measure the vref
	// a lot to make sure we know what value we are are targeting Ballparks
	//   (for unfiltered numbers)  (Just as a note)
	//   0xF0  / 240 for 5V input << lastrefvdd
	//	 0x175 / 373 for 3.3v input << lastrefvdd

	// Do an IIR low-pass filter on VDD. See IIR discussion above.
	uint32_t vdd = lastrefvdd = ADC1->IDATAR1 + (lastrefvdd - (lastrefvdd>>VDD_IIR));

#ifndef ENABLE_TUNING

	// If we aren't enabling tuning, we can update max on time here. We want to
	// limit on-time based on DC voltage on the flyback so that we can get
	// close to (But not get into) saturation of the flyback transformer's core
	//
	// We can compute expected values, but experimenting is better.
	// Transformer inductance is ~6uH.
	// Our peak current is ~500mA
	// The average voltage is ~4V
	//
	//   4V / .000006H = 0.5A / 666666A/s = 750nS but turns out this was
	//    pessemistic.
	//
	// Experimentation showed that the core of the transformer saturates in
	// about 1uS at 5V and 1.4uS at 3.3v.  More specifically the relationhip
	// between our maximum on-time and vref-measured-by-vdd works out to about:
	//
	//    max_on_time_slices = lastrefvdd / 4.44.
	//
	// There's a neat trick where you can divide by weird decimal divisors by
	// adding and subtracing terms. We perform this trick here and below
	//
	// 1÷(1÷4−1÷64−1÷128−1÷1024) is about equal to dividing by 4.43290
	//  It can be simplified it for our purposes as: 1÷(1÷4−1÷64−1÷128)
	//
	// You can arbitrarily add and subtract terms to get as closed to your
	// desired target value as possbile.
	//
	// When we divide a value by powers-of-two, it becomes a bit shift.
	//
	// The bit shift and IIR adjustments can be made so that the compiler can
	// optimize out the addition there.
	//
	// The following code actually
	pwm_max_duty = 
		  (lastrefvdd>>(2+VDD_IIR)) 
		- (lastrefvdd>>(6+VDD_IIR))
		- (lastrefvdd>>(7+VDD_IIR));
#endif

	// target_feedback is in volts. 0..200 maps to the device voltage.
	// lastrefvdd = 0xF0  for 5V input.
	// lastrefvdd = 0x175 for 3.3v input.
	//
	// feedback_vdd = 408 for ~192V @ 5
	// feedback_vdd = 680 for ~192V @ 3.3
	//
	// 408 = 192 * 240 / x = (192*240)/408 = 112.941176471
	// 680 = 192 * 373 / x = (373*680)/192 = 105.317647059
	//
	//  More tests showed this value across units is around 120.
	//
	// X This becomes our denominator.
	// feedback_vdd = (current vdd measurement * target voltage) / 120
	// 
	// Further testing identified that the denominator is almost exactly 120.
	// We can perform a divison by 120 very quickly by
	//
	//   feedback = numerator/128 + numerator/2048
	//
	// See note above about the constant division trick.
	//
	// Side-note:
	//
	// This is unintuitively slow becuase is because it uses a multiply. The
	// CH32V003 does not natively have a multiply instruction, If you use a *
	// it calls out to __mulsi3 in libgcc.a. 

	// The following line of code is still *more* than fast enough but, to
	// write it out manually, we can get even faster!
	//
	//	uint32_t numerator = (vdd * target_feedback);

	uint32_t numerator = FastMultiply( vdd, target_feedback );

	feedback_vdd =
		(numerator>>(7+VDD_IIR-ADC_IIR)) +
		(numerator>>(11+VDD_IIR-ADC_IIR));

	// Pet the watchdog.  If we got here, things should be OK.
	WatchdogPet();

	GPIOD->BSHR = (1<<(16+6));
}

static void SetupTimer1()
{
	// Enable Timer 1
	RCC->APB2PRSTR |= RCC_APB2Periph_TIM1;
	RCC->APB2PRSTR &= ~RCC_APB2Periph_TIM1;

	TIM1->PSC = 0x0000;  // Prescalar to 0x0000 (so, 48MHz base clock)
	TIM1->ATRLR = PWM_PERIOD;
	TIM1->CCER = TIM_CC2E | TIM_CC2NP;  // CH2 is control for FET.
	TIM1->CHCTLR1 = TIM_OC2M_2 | TIM_OC2M_1;

	TIM1->CH2CVR = 0;  // Actual duty cycle (Off to begin with)

	// Setup TRGO for ADC.  This makes is to the ADC will trigger on timer
	// reset, so we trigger at the same position every time relative to the
	// FET turning on.
	TIM1->CTLR2 = TIM_MMS_1;

	// Enable TIM1 outputs
	TIM1->BDTR = TIM_MOE;
	TIM1->CTLR1 = TIM_CEN;
}

static void SetupTimer2()
{
	// Enable Timer 2
	RCC->APB1PRSTR |= RCC_APB1Periph_TIM2;
	RCC->APB1PRSTR &= ~RCC_APB1Periph_TIM2;

	// PD7 will be used as Timer 2, Channel 4 Configure timer 2 to enable this.
	//TIM2->SWEVGR = 0x0001; 			//TIM_PSCReloadMode_Immediate;

	TIM2->PSC = 0x0020;
	TIM2->ATRLR = 255;				// 0..255 (So we can be 100% on)
	TIM2->CHCTLR2 = TIM_OC4M_2 | TIM_OC4M_1;
	TIM2->CCER = TIM_CC4E;
	TIM2->CH4CVR = 0;  			// Actual duty cycle (Off to begin with)

	// Enable TIM1 outputs
	TIM2->BDTR = TIM_MOE;
	TIM2->CTLR1 = TIM_CEN;
}

static void SetupADC()
{
	// Configure ADC.
	// PD4 is analog input chl 7
	GPIOD->CFGLR &= ~(0xf<<(4*4));	// CNF = 00: Analog, MODE = 00: Input
	
	// Reset the ADC to init all regs
	RCC->APB2PRSTR |= RCC_APB2Periph_ADC1;
	RCC->APB2PRSTR &= ~RCC_APB2Periph_ADC1;

	// ADCCLK = 12 MHz => RCC_ADCPRE divide by 4
	RCC->CFGR0 &= ~RCC_ADCPRE;  // Clear out the bis in case they were set
	RCC->CFGR0 |= RCC_ADCPRE_DIV4;	// set it to 010xx for /4.

	// Set up single conversion on chl 7
	ADC1->RSQR1 = 0;
	ADC1->RSQR2 = 0;
	ADC1->RSQR3 = 7;	// 0-9 for 8 ext inputs and two internals
	
	//Injection group is 8. NOTE: See note in 9.3.12 (ADC_ISQR) of TRM. The
	// group numbers is actually 4-group numbers.
	ADC1->ISQR = (8<<15) | (0<<20);

	// Sampling time for channels. Careful: This has PID tuning implications.
	// Note that with 3 and 3,the full loop (and injection) runs at 138kHz.
	ADC1->SAMPTR2 = (3<<(3*7)) | (3<<(3*8)); 
		// 0:7 => 3/9/15/30/43/57/73/241 cycles
		// (4 == 43 cycles), (6 = 73 cycles)  Note these are alrady /2, so 
		// setting this to 73 cycles actually makes it wait 256 total cycles
		// @ 48MHz.

	// Turn on ADC and set rule group to sw trig
	// 0 = Use TRGO event for Timer 1 to fire ADC rule.
	ADC1->CTLR2 = ADC_ADON | ADC_JEXTTRIG | ADC_JEXTSEL | ADC_EXTTRIG; 

	// Reset calibration
	ADC1->CTLR2 |= ADC_RSTCAL;
	while(ADC1->CTLR2 & ADC_RSTCAL);

	// Calibrate ADC
	ADC1->CTLR2 |= ADC_CAL;
	while(ADC1->CTLR2 & ADC_CAL);

	// enable the ADC Conversion Complete IRQ
	NVIC_EnableIRQ( ADC_IRQn );

	// ADC_JEOCIE: Enable the End-of-conversion interrupt.
	// ADC_JDISCEN | ADC_JAUTO: Force injection after rule conversion.
	// ADC_SCAN: Allow scanning.
	ADC1->CTLR1 = ADC_JEOCIE | ADC_JDISCEN | ADC_SCAN | ADC_JAUTO;
}

// Apply a given output mask to the GPIO ports the nixie tubes are hooked into.
static void ApplyOnMask( uint16_t onmask )
{
	GPIOD->OUTDR = (onmask >> 8) | 0x80;
	GPIOC->OUTDR = onmask & 0xff;
}

uint16_t GenOnMask( int segmenton )
{
	// Produce a bit mask with only one bit on. To indicate the IO to turn on
	// to light up a given segment.  If segmenton == 0, then all IO are off.
	if( segmenton > 0 )
	{
		segmenton--;
		if( segmenton < 8 )
			return 1<<segmenton;
		else if( segmenton == 8 )
			return (1<<2)<<8;
		else if( segmenton == 9 )
			return (1<<3)<<8;
		else if( segmenton == 10 )
			return (1<<0)<<8;
		else if( segmenton == 11 )
			return (1<<7)<<8;
	}
	return 0;
}

static void HandleCommand( uint32_t dmdword )
{
	// You can use minichlink to setup this:
	// ./minichlink -s 0x04 0x00B40041 # Configure for 180V.
	// ./minichlink -s 0x04 0x00030042 # Light digit "8"
	// ./minichlink -s 0x04 0x60303243 # Dimly light 8 and 8.
	// ./minichlink -g 0x04            # Get status.

	// Note: To get here, DEBUG0's LSB must be 0x4x command is that 'x'
	int command = dmdword & 0x0f;

	switch( command )
	{
	case 1:
	{
		int feedback = dmdword >> 16;
		if( feedback > ABSOLUTE_MAX_ADC_SET )
			feedback = ABSOLUTE_MAX_ADC_SET;
		target_feedback = feedback;
		break;
	}
	case 2:
	{
		int segmenton = (dmdword>>16)&0x0f;

		fade_time0 = -1;
		fade_time1 = -1;
		fade_disp0 = GenOnMask(segmenton);
		fade_disp1 = 0;
		break;
	}
	case 3:
	{
		// Configure a fade.
		fade_disp0 = GenOnMask( ( dmdword >> 8 ) & 0xf );
		fade_disp1 = GenOnMask( ( dmdword >> 12 ) & 0xf );
		fade_time0 = ( dmdword >> 16 ) & 0xff;
		fade_time1 = ( dmdword >> 24 ) & 0xff;
		break;
	}
	case 4:
	{
#ifdef ENABLE_TUNING
		// this is only for tuning.
		if( ( dmdword & 0xff00 ) == 0xaa00 )
		{
			int period = (dmdword>>16)&0xff;
			if( period < 20 ) period = 20;
			PWM_PERIOD = period;
			TIM1->ATRLR = PWM_PERIOD;
			int max_duty = (dmdword>>24)&0xff;
			if( max_duty > period - 14 ) max_duty = period - 14;
			pwm_max_duty = max_duty;
		}
#endif
		break;
	}
	case 5:
	{
		// Aux Neon Control
		TIM2->CH4CVR = dmdword>>16;
	}

	}

	// Write the status back to the host PC.  Status is our VDD and our FB V
	*DMDATA0 = ((lastadc>>ADC_IIR) << 12) | ((lastrefvdd>>VDD_IIR) << 22);
}

static inline void WatchdogPet()
{
	// Writing 0xaaaa into the ctlr prevents the watchdog from killing us.
	IWDG->CTLR = 0xAAAA;
}

static inline void WatchdogSetup()
{
	// Setup watchdog.
	IWDG->CTLR = 0x5555; // Go into watchdog setup mode.
	while( IWDG->STATR & IWDG_PVU ); // Wait for PSCR to become recepitve.
	IWDG->PSCR = 1;      // div LSI by 8 (4 seems unreliable)
	IWDG->RLDR = 0xFFF;  // reload watchdog, not important don't need to check.
	IWDG->CTLR = 0xCCCC; // commit registers.
	WatchdogPet();
}

static inline void AdvanceFadePlace()
{
	static uint32_t lastmask = 0;

	// Causes us to cycle through all 256 sequence points every 1.5ms.
	uint32_t fadepos = (SysTick->CNT >> 5) & 0xff;

	// We want to glow the LEDs with a chopping period of less, so we
	// "rotate" the bits.  This has the effect of making the primary
	// switching frequency for the tubes much higher, but, at the same time
	// also jittering the edges in time so you can get a full 8-bit fade.
	// You can rotate more or less to control the periodicity.

	// With this scramble, the period scramble is about 93us.
	fadepos = (fadepos << 4) | ( fadepos >> 4);

	uint32_t mask = HandleFade( fadepos );
	if( mask != lastmask )
	{
		if( lastmask )
		{
			// Make sure we have a short gap with nothing on.
			ApplyOnMask( 0 );
			Delay_Us( 3 );
		}
		ApplyOnMask( mask );
		lastmask = mask;
	}
}

int main()
{
	// Configure a watchdog timer so if the chip goes crazy it will reset.
	WatchdogSetup();

	// Use internall RC oscillator + 2xPLL to generate 48 MHz system clock.
	SystemInit48HSI();

	// For the ability to printf() if we want.
	SetupDebugPrintf();

	// Pet watchdog for the rest of startup.
	WatchdogPet();

	// Enable Peripherals
	RCC->APB2PCENR |= RCC_APB2Periph_GPIOD | RCC_APB2Periph_GPIOC |
		RCC_APB2Periph_GPIOA | RCC_APB2Periph_TIM1 | RCC_APB2Periph_ADC1 |
		RCC_APB2Periph_AFIO;

	RCC->APB1PCENR = RCC_APB1Periph_TIM2;

	// I'm paranoid - let's make sure all tube cathodes are high-Z.
	ApplyOnMask( 0 );

	GPIOD->CFGLR = 
		(GPIO_Speed_10MHz | GPIO_CNF_OUT_PP)<<(4*6) | // GPIO D6 Debug
		(GPIO_Speed_10MHz | GPIO_CNF_OUT_PP_AF)<<(4*7) | // DIG_AUX  (TIM2CH4)
		(GPIO_Speed_10MHz | GPIO_CNF_OUT_PP)<<(4*3) | // DIG_9
		(GPIO_Speed_10MHz | GPIO_CNF_OUT_PP)<<(4*2) | // DIG_8
		(GPIO_Speed_10MHz | GPIO_CNF_IN_FLOATING)<<(4*1) | // PGM Floats.
		(GPIO_Speed_10MHz | GPIO_CNF_OUT_PP)<<(4*0);  // DIG_DOT

	GPIOC->CFGLR = 
		(GPIO_Speed_10MHz | GPIO_CNF_OUT_PP)<<(4*0) | // DIG_0
		(GPIO_Speed_10MHz | GPIO_CNF_OUT_PP)<<(4*1) | // DIG_1
		(GPIO_Speed_10MHz | GPIO_CNF_OUT_PP)<<(4*2) | // DIG_2
		(GPIO_Speed_10MHz | GPIO_CNF_OUT_PP)<<(4*3) | // DIG_3
		(GPIO_Speed_10MHz | GPIO_CNF_OUT_PP)<<(4*4) | // DIG_4
		(GPIO_Speed_10MHz | GPIO_CNF_OUT_PP)<<(4*5) | // DIG_5
		(GPIO_Speed_10MHz | GPIO_CNF_OUT_PP)<<(4*6) | // DIG_6
		(GPIO_Speed_10MHz | GPIO_CNF_OUT_PP)<<(4*7);  // DIG_7


	GPIOA->CFGLR =
		(GPIO_Speed_50MHz | GPIO_CNF_OUT_PP_AF)<<(4*1); //FLYBACK (T1CH2)

	SetupADC();
	SetupTimer1();
	SetupTimer2();

	*DMDATA0 = 0;

	target_feedback = 0;

	// Cause system timer to run and reload when it hits CMP and HCLK/8.
	// Also, don't stop at comparison value.
	SysTick->CTLR = 1;

	while(1)
	{
		uint32_t dmdword = *DMDATA0;
		if( (dmdword & 0xf0) == 0x40 )
		{
			// I think there is a compiler bug here.  For some reason if I put
			// the code in this function right here, it doesn't work right.
			// so I encapsulated the code in a function.
			//
			// This function handles commands we get over the programming
			// interface.  Like "set HV bus" or "set this digit on."
			HandleCommand( dmdword );
		}

		AdvanceFadePlace();

	}
}

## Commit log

2023-01-23 Add initial commit, thoughts.
    [esp32s2-nixietube.kicad_pcb, esp32s2-nixietube.kicad_sch]
2023-04-13 Add test board
    [nixitest1.kicad_pcb, nixitest1.kicad_sch]
2023-04-13 Add flyback.
    [nixitest1.kicad_pcb, nixitest1.kicad_sch]
2023-04-14 Update design.
    [nixitest1.kicad_pcb, nixitest1.kicad_sch]
2023-04-14 Ok actually ready for production.
    [nixitest1.kicad_pcb, nixitest1.kicad_sch]
2023-04-19 Add start of nixiehost
    [esp32s2-nixiehost.kicad_pcb, esp32s2-nixiehost.kicad_sch]
2023-04-20 Bump to rel ver
    [esp32s2-nixiehost.kicad_pcb, esp32s2-nixiehost.kicad_sch]
2023-04-21 Update comments on nixietest + Add debug tool. + Add ch32v003 firmware for the controller.
    [nixitest1.kicad_sch]
2023-04-21 Update board design
    [nixitest1.kicad_pcb, nixitest1.kicad_sch]
2023-04-21 General update for all
    [nixitest1.kicad_sch]
2023-04-22 Update projects with notes. Allow for tuning.
    [nixitest1.kicad_sch]
2023-04-22 100% working! Variable input voltage.
2023-04-23 * Revert pcb so it matches production files. * Move original thoughts into attic. * Update comments on firmware
    [esp32s2-nixietube.kicad_pcb, esp32s2-nixietube.kicad_sch, nixitest1.kicad_pcb]
2023-04-23 Try switching to a 12MHz ADC clock as per recommendations in datasheet.
2023-04-23 Good tuning parameters across whole voltage range.
2023-04-24 Update design based on tests of first rev.
    [nixitest1.kicad_pcb, nixitest1.kicad_sch]
2023-04-24 Forgot to mention testing orientation differences?
    [nixitest1.kicad_sch]
2023-04-25 Improve perf of adc interrupt + retune
2023-04-25 retuned to prevent hissing.
    [nixitest1.c]
2023-04-25 Update schematic and design.
    [nixitest1.kicad_pcb, nixitest1.kicad_sch]
2023-04-25 Add note about assembly.
2023-04-27 Adjust resistors to reduce max power to neons and period.
    [nixitest1.kicad_sch]
2023-04-30 Updte with schematic.
    [nixitest1.kicad_pcb]
2023-04-30 Tweak pins.
    [nixitest1.kicad_pcb]
2023-04-30 Update footprints to shrink holes for standoffs.
    [nixitest1.kicad_pcb]
2023-05-06 Update, switching to srodata.
2023-05-06 Add windows buttons.
2023-06-08 Update to rev B.
    [nixitest1.kicad_pcb, nixitest1.kicad_sch]
2023-06-09 Update schematic etc for rev b.
    [nixitest1.kicad_sch]
2023-06-09 Update holes for tubes.
2024-04-25 Fix incorrect timer 2 setup note.
    [nixitest1.c]
2025-08-04 Update with schematic etc.
